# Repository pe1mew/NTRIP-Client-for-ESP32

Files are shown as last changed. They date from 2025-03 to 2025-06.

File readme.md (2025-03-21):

# NTRIP-Client-for-ESP32.

This repository contains the progress in developing a NTRIP client on a ESP32 for the HAN Hydromotive racingteam. 

## License and disclaimer. 

Please note the license at the end of this document. 

# License
This project is free: You can redistribute it and/or modify it under the terms of a Creative Commons Attribution-NonCommercial 4.0 International License (http://creativecommons.org/licenses/by-nc/4.0/) by Remko Welling (https://ese.han.nl/~rwelling) E-mail: remko.welling@han.nl

<br />This work is licensed under a <a rel="license" href="http://creativecommons.org/licenses/by-nc/4.0/">Creative Commons Attribution-NonCommercial 4.0 International License</a>.

# Disclaimer
This project is distributed in the hope that it will be useful, but WITHOUT ANY WARRANTY; without even the implied warranty of MERCHANTABILITY or FITNESS FOR A PARTICULAR PURPOSE.

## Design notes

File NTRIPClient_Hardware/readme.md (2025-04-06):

# Boards

The following boards are under consideration: 

- Wemos S3 - ESP32-S3 https://www.tinytronics.nl/nl/development-boards/microcontroller-boards/met-wi-fi/wemos-s3-esp32-s3
- Waveshare ESP32-S3 Pico Development Board https://www.tinytronics.nl/nl/development-boards/microcontroller-boards/met-wi-fi/waveshare-esp32-s3-pico-development-board

# Architecture

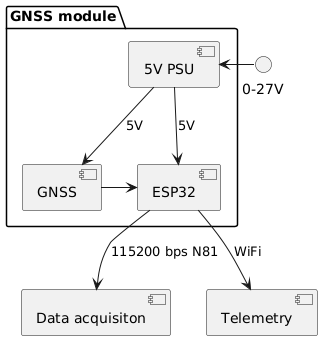
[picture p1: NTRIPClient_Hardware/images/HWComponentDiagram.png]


*figure 1: Component diagram*

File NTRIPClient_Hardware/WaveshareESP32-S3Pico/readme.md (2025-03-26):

# Waveshare ESP32-S3 Pico Development Board

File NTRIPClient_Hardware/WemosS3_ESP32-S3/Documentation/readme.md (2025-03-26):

# Wemos S3 ESP32-S3 documentation 

The following documents have been retrieved from https://www.wemos.cc/en/latest/s3/s3.html at 26-3-2025
 - dim_s3_v1.0.0.pdf
 - esp32-s3-wroom-1_wroom-1u_datasheet_en.pdf
 - s3_v1.0.0_1_16x16.jpg
 - s3_v1.0.0_2_16x16.jpg
 - s3_v1.0.0_4_16x9.jpg
 - sch_s3_v1.0.0.pdf
 
The following documents have been retrieved from https://probots.co.in/esp32-s3-devkitc-1-development-board-wireless-module-wifi-bluetooth.html at 26-3-2025
 - \_ESP32-S3-DevKitC_Dimensions.jpg

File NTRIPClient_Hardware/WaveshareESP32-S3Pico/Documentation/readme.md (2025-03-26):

# Documentation

[Wiki](https://www.waveshare.com/wiki/ESP32-S3-Pico) https://www.waveshare.com/wiki/ESP32-S3-Pico

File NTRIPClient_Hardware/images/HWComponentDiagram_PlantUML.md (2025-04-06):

# PLantUML code for component diagram HWComponentDiagram.png



```
@startuml

package "GNSS module" {
  [5V PSU]
  [GNSS]
  [ESP32]
}

[GNSS] -right-> [ESP32]
[ESP32] --> [Data acquisiton] : 115200 bps N81
[ESP32] --> [Telemetry] : WiFi
[5V PSU] --> [ESP32] : 5V
[5V PSU] --> [GNSS] : 5V

"0-27V" -right-> [5V PSU]

@enduml
```

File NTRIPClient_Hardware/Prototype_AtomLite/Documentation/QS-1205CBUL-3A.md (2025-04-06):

# DC-DC Step Down Module 6-24V 12V 24V to 5V 3A Power Supply Charger QS-1205CBUL-3A



 - Brand: QSKJ
 - Model: [QS-1205CBUL-3A](https://www.qskj.cc/shop/dc-dc-step-down-module-6-24v-12v-24v-to-5v-3a-power-supply-charger-qs-1205cbul-3a-6687)
 
## Images.

 - [QS-1205CBUL-3A_top.jpg](QS-1205CBUL-3A_top.jpg)
 - [QS-1205CBUL-3A_front.jpg](QS-1205CBUL-3A_front.jpg)
 - [QS-1205CBUL-3A_bottom.jpg](QS-1205CBUL-3A_bottom.jpg)

## Features:

 - High quality USB port.
 - Output voltage indicator (RED).
 - The max output current 3A, long time use 2.1A, enough use.
 - New design, 3 solid state ceramic capacitors (MLCC).
 - Synchronous rectification, High efficiency, 6.5V to 5V 0.7A can up to 97.5%, 12V to 5V 1A can up to 94%.
 - Flat copper inductor, improve conversion efficiency
 - With output overvoltage protection. There is 1.5A fuse, output 5V have 300W TVS tube protect your USB device.
 - Using the latest USB identification circuit, perfectly compatible with IPHONE, the most of Android phones, IPAD etc.
 - Input with reverse polarity protection diode, will not damage when input connect incorrect.

## Parameters:

 - Input voltage: DC 6-24V
 - Output voltage: 5.1-5.2V
 - Output current: 3A MAX 
 - Switch frequency:  500KHz
 - Size：26.4(L)*15(W)*7.4(H)  mm
 - Output ripple: 10mV around (12V to 5V3A) 20M bandwidth
 - Output indicator: Output voltage indicator is red
 - Full load temperature: 30 Celsuis
 - Static current: 0.85 mA
 - Load regulation:  ± 1%
 - Voltage Regulation:  ± 0.5%
 - Dynamic response speed:  5% 200uS
 - Connection mode:  Welding
 - Input mode:  Welding
 - Output mode: US
 - Output overvoltage protection: Yes, input 1.5A fuse, output 5V have 300W TVS tube clamp protection.
 - Output short circuit protection: Yes, but please do not short circuit for a long time
 - Input reverse polarity protection: Yes, there is reverse polarity protection diode
 - Module Properties:  non-isolated buck module (BUCK) synchronous rectification
 - Conversion efficiency:  can up to 97.5% (6.5V step down to 5V 0.7A) (after short reverse protection and fuses test value)
 - Ultra-low static current, 0.85 mA only. Do not need to add swith when connected to the car battery, can be connected to car cigarette lighter cable or ACC power supply cable.
 - Operating temperature: Industrial grade (-40 Celsuis to + 85 Celsuis) (the higher the ambient temperature, the lower the output power)

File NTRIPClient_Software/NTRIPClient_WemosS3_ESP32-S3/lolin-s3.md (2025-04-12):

# Key Pin Assignments for LOLIN S3:

UART (Serial Communication):
 - UART0 (Default Serial):
   - TX: GPIO1
   - RX: GPIO3
 - UART1:
   - TX: GPIO19
   - RX: GPIO20
 - UART2:
   - TX: GPIO17
   - RX: GPIO18

I2C (Default):
 - SDA: GPIO8
 - SCL: GPIO9

SPI (Default):
 - SCK:  GPIO36
 - MISO: GPIO37
 - MOSI: GPIO35
 - CS:   GPIO34

WS2812 RGB LED:
 - Data Pin: GPIO38 (Onboard WS2812 RGB LED)

Buttons:
 - BOOT Button: GPIO0 (Can be used as an input)

Analog Pins (ADC):
 - ADC1: GPIO1, GPIO2, GPIO3, GPIO4, GPIO5, GPIO6, GPIO7
 - ADC2: GPIO10, GPIO11, GPIO12, GPIO13, GPIO14, GPIO15

PWM (LED Control):
 - Any GPIO pin can be used for PWM output.

Power Pins:
 - 5V: 5V pin
 - 3.3V: 3.3V pin
 - GND: Ground pins

Other Pins:
 - GPIO38: Onboard WS2812 RGB LED
 - GPIO39: Input-only pin (can be used for buttons or sensors)

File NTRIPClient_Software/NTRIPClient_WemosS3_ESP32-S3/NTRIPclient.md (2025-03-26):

# NTRIP Client Operation Manual

## Introduction
The NTRIP (Networked Transport of RTCM via Internet Protocol) client is designed to receive RTCM correction data from an NTRIP caster, provide it to GNSS receivers for improved positioning accuracy, and send position information of the GNSS receiver to a MQTT broker. 

## Requirements
- A device running the NTRIP client firmware (e.g., ATOM Lite).
- Access to an NTRIP caster with valid credentials (host, port, username, password, and mountpoint).
- Access to an MQTT broker with valid credentials (host, port, username, password, and topic).
- A stable internet connection (Wi-Fi or other supported methods).
- A GNSS receiver capable of processing RTCM correction data.

## Setup Instructions

### 1. Configure Wi-Fi
1. When the NTRIP client boots up, it tries to connect to a previously saved WiFi network.
2. If no known network is found, it creates a WiFi Access Point (AP) with:
   - **SSID**: "NTRIPClient_Config"
   - **Password**: none
3. Connect your phone or computer to this network.
4. Open a browser and go to 192.168.4.1.
5. Select your WiFi network, enter the password, and save the settings.

When the NTRIP client is connected to a WiFi network:
1. the config menu can be invoked by pressing the button on the NTRIP client for more than 3 seconds. 
2. Connect your computer to the same network as the NTRIP client. 
3. Open a browser and go to the IP-address of the NTRIP client. 
4. Select a WiFi network, enter the password, and save the settings.

### 2. Configure NTRIP Caster Details
1. Provide the following details for the NTRIP caster:
   - **Host**: The hostname or IP address of the NTRIP Caster (e.g., `caster.example.com`)
   - **Port**: The port number for the NTRIP caster (e.g., `2101`)
   - **Mountpoint**: Name of the moint point where the RTCM data will be retrieved (e.g., `RTCM3`)
   - **Username and password**: Credentials for authenticating with the NTRIP Caster (if required)
2. Save the configuration.

### 3. Start the NTRIP Client
1. Initiate the connection to the NTRIP caster.
2. Verify that the device successfully connects and starts receiving RTCM data.

### 4. Connect to GNSS Receiver
1. Ensure the GNSS receiver is properly connected to the device (e.g., via UART or other supported interfaces).
2. Verify that the GNSS receiver is receiving RTCM correction data.

### 5. Configure MQTT Client
1. Access the device's configuration interface.
2. Provide the following MQTT broker details:
   - **Broker Address**: The hostname or IP address of the MQTT broker (e.g., `mqtt.example.com`).
   - **Port**: The port number for the MQTT broker (e.g., `1883`).
   - **Username and Password**: Credentials for authenticating with the MQTT broker (if required).
   - **Topic**: The MQTT topic where the device will publish data (e.g., `ntrip/status`).
3. Save the configuration.

### Purpose of MQTT Client
The MQTT client allows the NTRIP client to publish status updates and diagnostic information to an MQTT broker. This enables remote monitoring and integration with IoT platforms or dashboards.

### JSON Structure of Published Data
The NTRIP client publishes data in JSON format to the configured MQTT topic. Below is the structure of the JSON payload:

```json
{
  "timestamp": "2023-01-01T12:00:00Z", // ISO 8601 timestamp of the message
  "status": "connected",              // Current connection status (e.g., "connected", "disconnected")
  "ntrip": {
    "host": "caster.example.com",     // NTRIP caster hostname
    "port": 2101,                     // NTRIP caster port
    "mountpoint": "RTCM3"             // NTRIP mountpoint in use
  },
  "gnss": {
    "rtcm_received": true,            // Whether RTCM data is being received
    "last_rtcm_time": "2023-01-01T11:59:50Z" // Timestamp of the last RTCM message received
  }
}
```

### Example Use Case
- Use the MQTT data to monitor the connection status of the NTRIP client.
- Integrate the JSON payload into a dashboard to visualize real-time data.
- Trigger alerts if the client disconnects or stops receiving RTCM data.

## Troubleshooting
- **No Internet Connection**: Check Wi-Fi credentials and signal strength.
- **Failed to Connect to NTRIP Caster**: Verify the host, port, and credentials.
- **No RTCM Data on GNSS Receiver**: Check the connection between the device and the GNSS receiver.

## Additional Notes
- Ensure the device's firmware is up-to-date for optimal performance.
- Contact your NTRIP caster provider for assistance with credentials or mountpoint details.

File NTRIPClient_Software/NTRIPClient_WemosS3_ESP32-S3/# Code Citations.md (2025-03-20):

# Code Citations

## License: LGPL_3_0
https://github.com/GLAY-AK2/NTRIP-client-for-Arduino/tree/875298f5fa1c4ec84929b0c54364f77d5df7e081/src/NTRIPClient.cpp

```
0\r\n"
        "User-Agent: NTRIPClient for Arduino v1.0\r\n"
    );
    unsigned long timeout = millis();
    while (available() == 0) {
        if (millis() - timeout > 5000) {
            Serial.
```

## License: unknown
https://github.com/heyno/arduino/tree/143c22816d5a8fa4521b3c6ef67941aee86f4876/libraries/NTRIP-client-for-Arduino-master/src/NTRIPClient.cpp

```
Arduino v1.0\r\n"
    );
    unsigned long timeout = millis();
    while (available() == 0) {
        if (millis() - timeout > 5000) {
            Serial.println("Client Timeout !");
            stop();
```

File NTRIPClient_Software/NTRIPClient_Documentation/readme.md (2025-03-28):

# Software manual NTRIP Client

The NTRIP client is developed for the [Hydromotive project](https://www.hydromotive.nl/) to enable cm precison location and timing. 

The **NTRIP client** (Networked Transport of RTCM via Internet Protocol) is used to receive real-time correction data for a **GNSS (Global Navigation Satellite System)** receiving. By connecting to an **NTRIP caster** (a server that distributes correction data from an NTRIP base station or network) the NTRIP data is received and forwarded to the connected GNSS receiver.

The position and timing information from the GNSS receiver is published using the **MQTT (Message Queuing Telemetry Transport)** protocol on a **MQTT broker** for post processing purposes and live monitoring. 

### **How this NTRIP client Works:**
1. The **GNSS receiver** connects to an **NTRIP client**.
2. The **NTRIP client** sends a request to an **NTRIP caster** over the internet.
3. The **NTRIP caster** provides **RTCM correction data** from a nearby base station or network.
4. The **GNSS receiver** uses this data to correct its position in real time.
5. The **MQTT client** connects to an **MQTT broker** (server).
6. The **MQTT client** **subscribes** to a topic (e.g., "ntripclient").
7. The **MQTT client** publishes position and timing data to the topic
8. The broker **forwards** messages to all subscribed clients that use the data.
9. The **MQTT client** publishes time data to the data ackuisition unit of the Hydromotive vehicle. 

# NTRIP Client operation.
After powering the NTRIP Client, WiFi connection is initiated. At a successfull WiFi connection, the NTRIP caster is connected and the mountpoint table is requested. When the mointpoint table is received, the mointpoint is connected and RTCM data that is received will be forwarded to the GNSS receiver. When a valid set of NMEA sentences is received from the GNSS receiver, a aggregate of time, postion and accuracy data is send to the MQTT broker. 

### WiFi Connection failure
When the **Wifi connection fails at startup**, a WiFi accesspoint and the configuration portal is activated. The configuration panel can be accesses after connecting to the Accesspoint and ip-address 192.168.4.1.

When the **WiFi connection fails during operation**, reconnects are attempted. After a period of time, a WiFi accesspoint and the configuration portal is activated for configuration. 

### Connection failure with NTRIP caster 
When the **Connection fails with the NTRIP caster**, a restart of the NTRIP Client is executed to attempt to recover the connection.

### Connection failure with MQTT broker
When the **Connection fails with the MQTT broker**, an attempt is made to reconnect. Because NTRIP correction data for the GNSS receiver has priority over MQTT, the ocnnection NTRIP is retained and the NTRIP Client will not restart. 

### NTRIP Client Configuration
> The NTRIP Client can be configured from Platform.io by writing the config file `config.json` in de `data` directory to SPIFFS. Instructions can be found in `data_template/readme.md`.

The NTRIP Client can be configured using WiFi manager: 
 - During normal operation, WiFi manager can be activated by **pressing the config-button longer than 3 seconds**. 
 - When WiFi the connection fails, an Accesspoint is activated where the WiFi manager can be accessed. 

# WiFi manager

WiFi Manager manages al configureable items of the NTRIP Client in a browser. The WiFi manager is invoked after a connect failure of the WiFi at boot, or after pressing the **Configuration button** for a period longer than 3 seconds. 

In the following paragraphs the menus of WiFi manager are discussed.

## Main menu

Main memu is the start screen when entering WiFi manager.

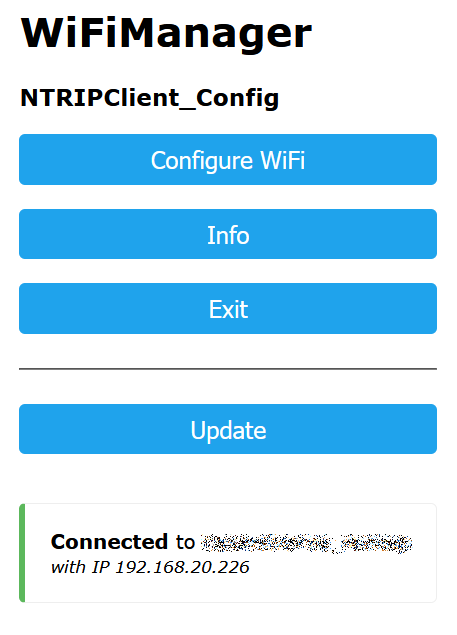
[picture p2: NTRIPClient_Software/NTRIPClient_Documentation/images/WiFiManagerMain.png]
WiFiManager


*Figure 1: Main menu of WiFimanager for NTRIP Client.*

The main menu allows access to the following screens: 
 1. **Configure WiFi**: Configure NTRIP Client settings. 
 2. **Info**: System information. 
 3. **Exit**: Store settings and reboot NTRIP client. 
 4. **Update**: Update software image.
 
## Configure NTRIP Client settings

WiFi manager allows for full configuration of the NTRIP Client. The following parameters can be configured using Wifi manager: 

 - WiFi:
   - **ssid**: SSID of the WiFi Accesspoint
   - **password**: Password for the WiFi Accesspoint
 - NTRIP Client:
   - **host**: hostname of the NTRIP Caster
   - **tcp-port**: tcp-port for the broker *(Default: 2101)*
   - **mntpnt**: mountpoint
   - **username**: username for the NTRIP caster
   - **password**: password for the user
 - MQTT Client:
   - **broker**: *IP-address* of the MQTT broker **(No URL!)**
   - **port**: tcp-port for the broker *(Default: 1883)*
   - **topic**: Topic where the data will be published *(e.g. ntripclient)*
   - **username**: username for the MQTT broker
   - **password**: password for the user

The configuration items are permanently stored on the NTRIP Client. 

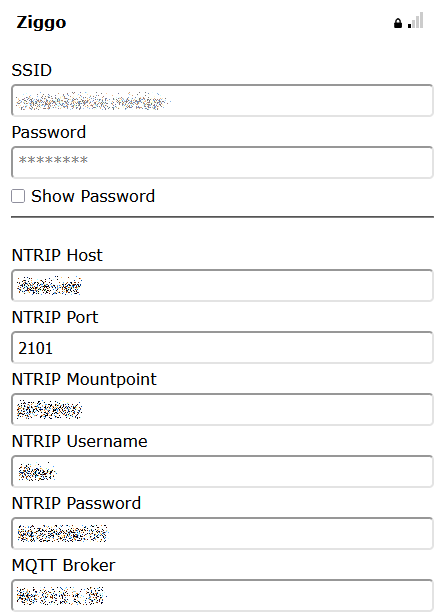
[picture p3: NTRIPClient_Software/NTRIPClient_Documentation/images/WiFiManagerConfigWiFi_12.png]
WiFiManagerConfigWiFi_12

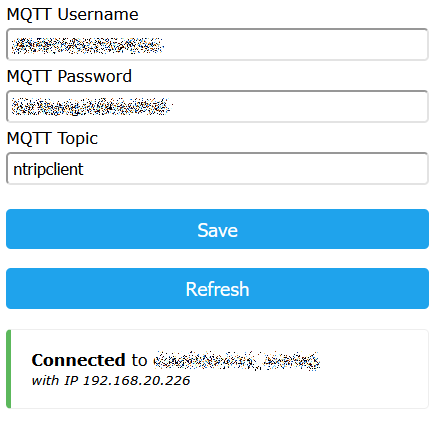
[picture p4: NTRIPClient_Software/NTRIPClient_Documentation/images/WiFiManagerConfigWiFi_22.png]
WiFiManagerConfigWiFi_12


*Figure 2: Settings menu of WiFi manager for NTRIP Client.*

## Info

WiFi manager shows system information of the NTRIP Client: 

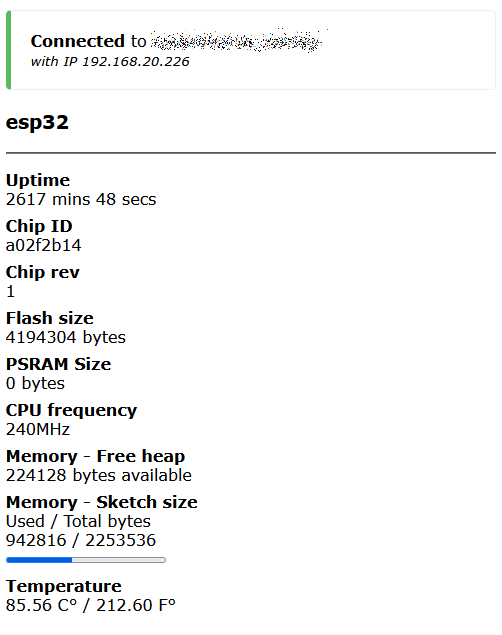
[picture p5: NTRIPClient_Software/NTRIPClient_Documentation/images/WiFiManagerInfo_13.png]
WiFiManagerInfo_13

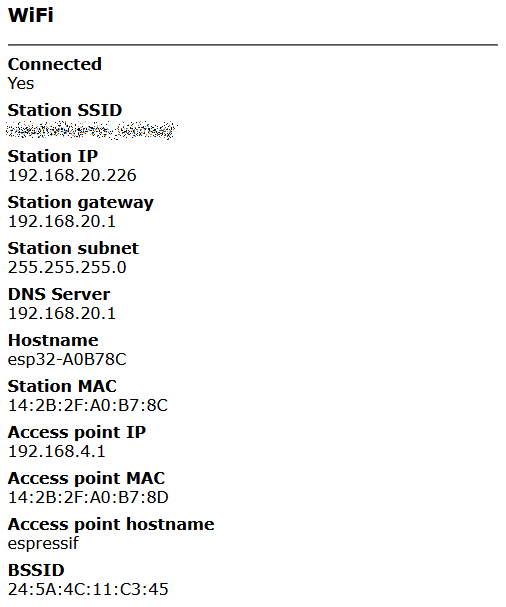
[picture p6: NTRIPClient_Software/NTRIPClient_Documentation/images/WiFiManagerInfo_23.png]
WiFiManagerInfo_23

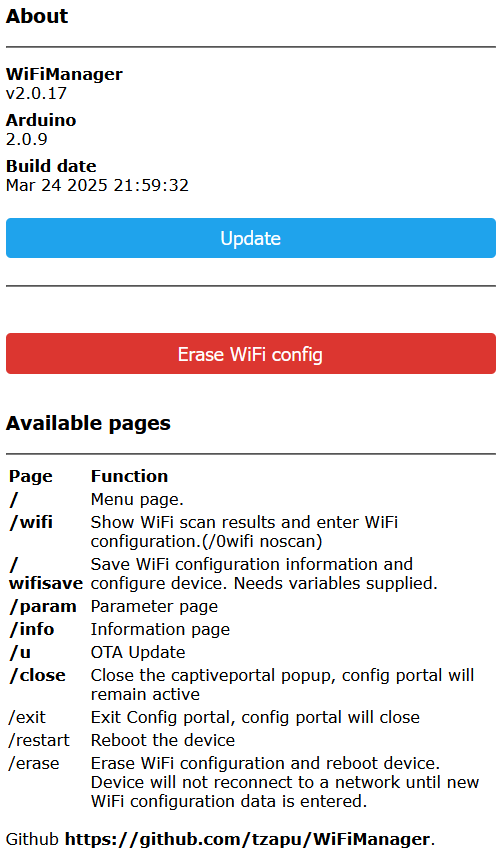
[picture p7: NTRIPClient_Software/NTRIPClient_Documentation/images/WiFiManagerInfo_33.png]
WiFiManagerInfo_33


*Figure 3: Information menu of WiFi manager for NTRIP Client.*

## Exit

To close WiFo manager, click **Exit** to save teh settings and restart NTRIP Client. 

## Update

In the Update menu the firmware of the NTRIP Client can be updated. 
> **This feature is not tested. Use with care!**

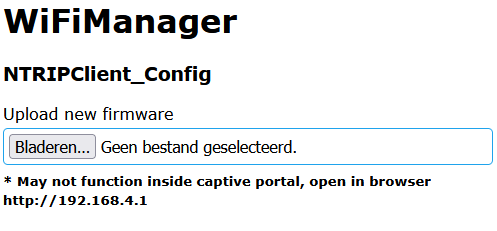
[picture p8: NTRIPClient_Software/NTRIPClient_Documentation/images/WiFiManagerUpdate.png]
WiFiManagerUpdate


*Figure 4: Update menu of WiFi manager for NTRIP Client.*

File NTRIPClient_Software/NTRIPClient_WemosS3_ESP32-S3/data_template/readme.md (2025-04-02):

# Configuration file config.json

The `config.json` file is used to store the settings required for the Ntrip client to function properly. It contains three main sections: `wifi`, `ntrip`, and `mqtt`. 

```json
{
    "wifi": {
        "ssid": "ssid",
        "password": "wifi_password"
    },
    "ntrip": {
        "host": "host",
        "port": 2101,
        "mntpnt": "mountpoint",
        "user": "ntrip_user",
        "passwd": "ntrip_user_password"
    },
    "mqtt": {
        "broker": "broker",
        "port": 1883,
        "topic": "ntripclient",
        "user": "mqtt_user",
        "passwd": "mqtt_user_password"
    }
}
```

## Configuration Details

Below is a detailed explanation of each section and its name-value pairs:

### WiFi Configuration (`wifi`)
- **ssid**: The SSID (name) of the WiFi network to connect to.
- **password**: The password for the WiFi network.

### NTRIP Configuration (`ntrip`)
- **host**: The hostname or IP address of the NTRIP caster.
- **port**: The port number of the NTRIP caster (default is usually 2101).
- **mntpnt**: The mountpoint to connect to on the NTRIP caster.
- **user**: The username for NTRIP authentication.
- **passwd**: The password for NTRIP authentication.

### MQTT Configuration (`mqtt`)
- **broker**: The *IP address* of the MQTT broker. *The hostname of the broker cannot be used here!*
- **port**: The port number of the MQTT broker (default is 1883).
- **topic**: The MQTT topic to publish or subscribe to.
- **user**: The username for MQTT authentication.
- **passwd**: The password for MQTT authentication.

## Instructions

### Step 1: Prepare the Configuration File
1. Copy the directory `data_template` and its contents to a new directory named `data`.
2. Open `data/config.json` and update the values for `wifi`, `ntrip`, and `mqtt` with the required credentials and settings for your environment.

### Step 2: Remove Unnecessary Files
- Delete the file `data/readme.md` to ensure it is not uploaded to the SPIFFS filesystem.

### Step 3: Upload the Configuration to the ESP32
1. Open a terminal in PlatformIO.
2. Run the following command to compile and upload the SPIFFS filesystem to your ESP32:
   ```bash
   pio run --target uploadfs
   ```
3. Once the upload is complete, the ESP32 will use the settings from `config.json` to connect to the WiFi network, NTRIP caster, and MQTT broker.

### Notes
- Ensure that the ESP32 has sufficient permissions and connectivity to access the specified WiFi network, NTRIP caster, and MQTT broker.
- Double-check the JSON syntax in `config.json` to avoid errors during runtime.

This configuration file allows the Ntrip client to operate seamlessly by providing all necessary credentials and connection details in one place.

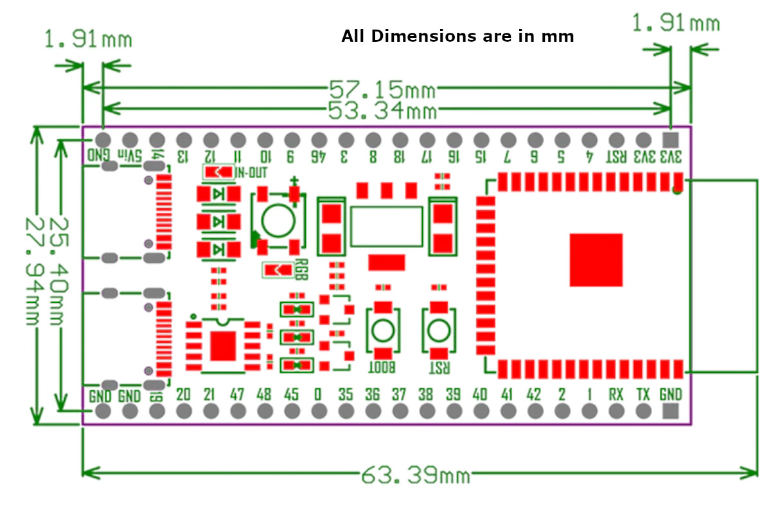
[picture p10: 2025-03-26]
NTRIPClient_Hardware/WemosS3_ESP32-S3/Documentation/_ESP32-S3-DevKitC_Dimensions.jpg

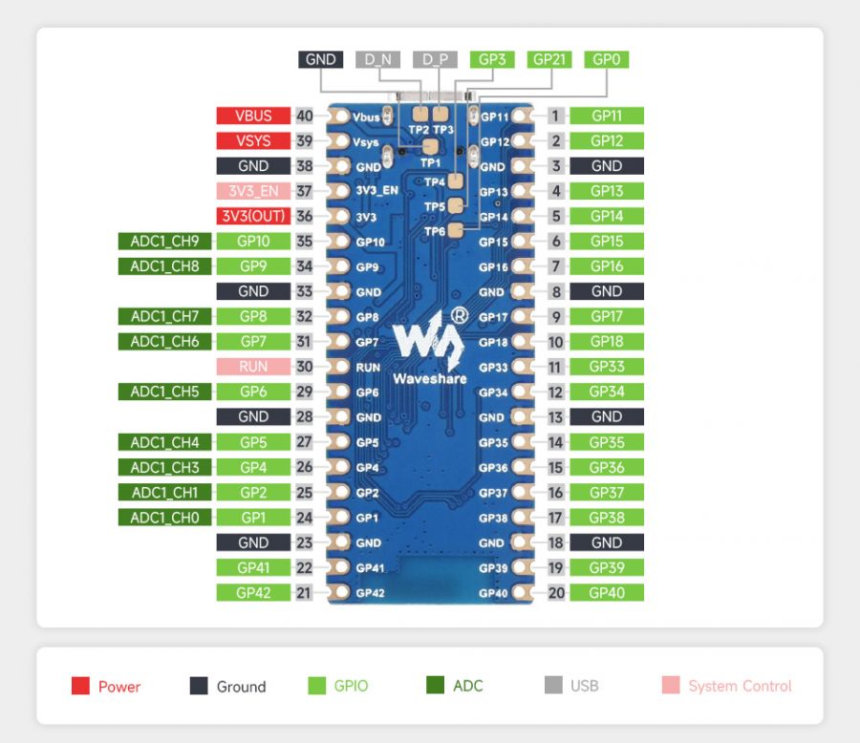
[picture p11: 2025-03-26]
NTRIPClient_Hardware/WaveshareESP32-S3Pico/Documentation/900px-ESP32-S3-Pico-details-inter-1.jpg

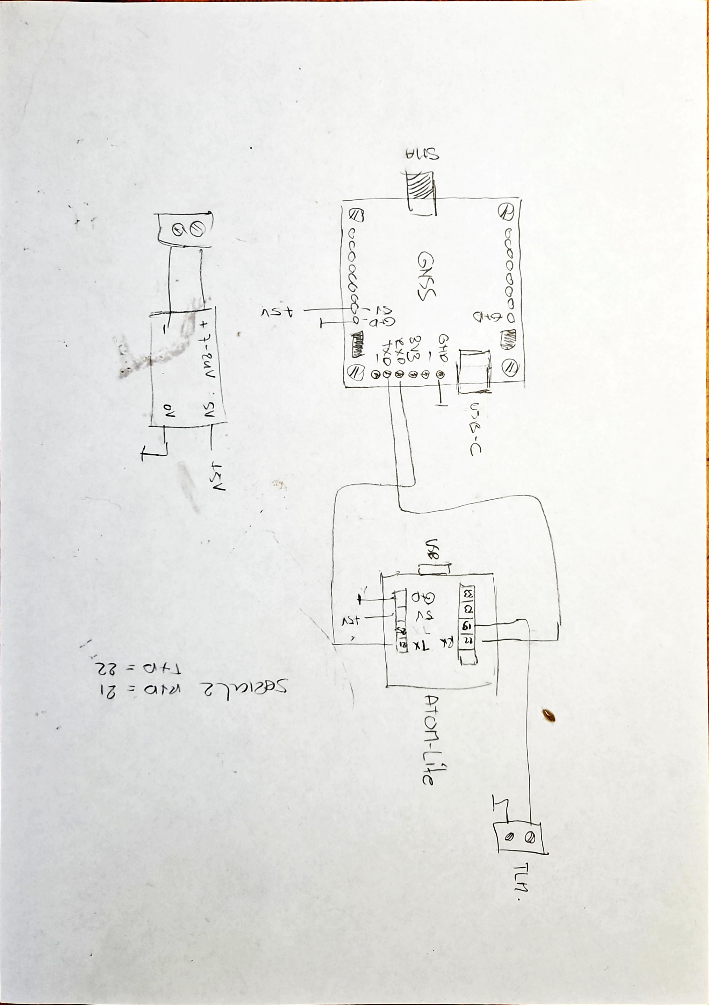
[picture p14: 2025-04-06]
NTRIPClient_Hardware/Prototype_AtomLite/Documentation/PrototypeSchema.jpg

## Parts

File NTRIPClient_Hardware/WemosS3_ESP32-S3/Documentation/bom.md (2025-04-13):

RS PRO, 5.08mm Pitch, 4 Way, Right Angle, Pluggable Terminal Block, Plug, Through Hole, Screw Termination
RS-stocknr.: 897-1216
Fabrikant: RS PRO
https://nl.rs-online.com/web/p/pluggable-terminal-blocks/8971216
1,33 \* 5

RS PRO, 5mm Pitch, 4 Way, , Pluggable Terminal Block, Header, Through Hole, Screw Termination
RS-stocknr.: 144-4283
Fabrikant: RS PRO
https://nl.rs-online.com/web/p/pluggable-terminal-blocks/1444283
0,434 \* 10

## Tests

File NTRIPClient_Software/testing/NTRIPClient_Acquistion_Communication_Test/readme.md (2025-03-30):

# NTRIPClient --> Acquistion unit, Communication Test

This unit test, tests the CRC-16 calculation for the day-time-stamp that is sent to the Acquistion unit by the NTRIP client.

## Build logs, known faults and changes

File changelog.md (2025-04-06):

# Changelog

All notable changes to this project are documented in this file.

The format is based on [Keep a Changelog](https://keepachangelog.com/), and this project adheres to [Semantic Versioning](https://semver.org/).

## [Unreleased]

### Added
- *Nothing.*

### Changed
- *Nothing.*

### Fixed
- *Nothing.*

### Removed

## [Version 0.0.1] - 2025-04-06

### Added
- Connects over WiFi to the internet. 
- Receives NTRIP data from caster and forwards to GNSS module.
- Forwards postion data and metadata over MQTT to a broker.
- Sends siral timestamp with CRC-16 over serial port.
- WiFi, NTrip-client, and MQTT-client ar configureable over WiFi Manager.

### Changed
- *Nothing.*

### Fixed
- *Nothing.*

### Removed
- *Nothing.*

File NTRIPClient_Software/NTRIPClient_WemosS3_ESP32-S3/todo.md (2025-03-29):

# Todolist for software

29-3-2025

|#|**Done**  |**Description** |
|-|---|---|
|1|23-3-3035 |Convert lat in MQTT message to DD.DDDDDDDDDD|
|2|29-3-2025-|Convert lon in MQTT message to DD.DDDDDDDDDD|

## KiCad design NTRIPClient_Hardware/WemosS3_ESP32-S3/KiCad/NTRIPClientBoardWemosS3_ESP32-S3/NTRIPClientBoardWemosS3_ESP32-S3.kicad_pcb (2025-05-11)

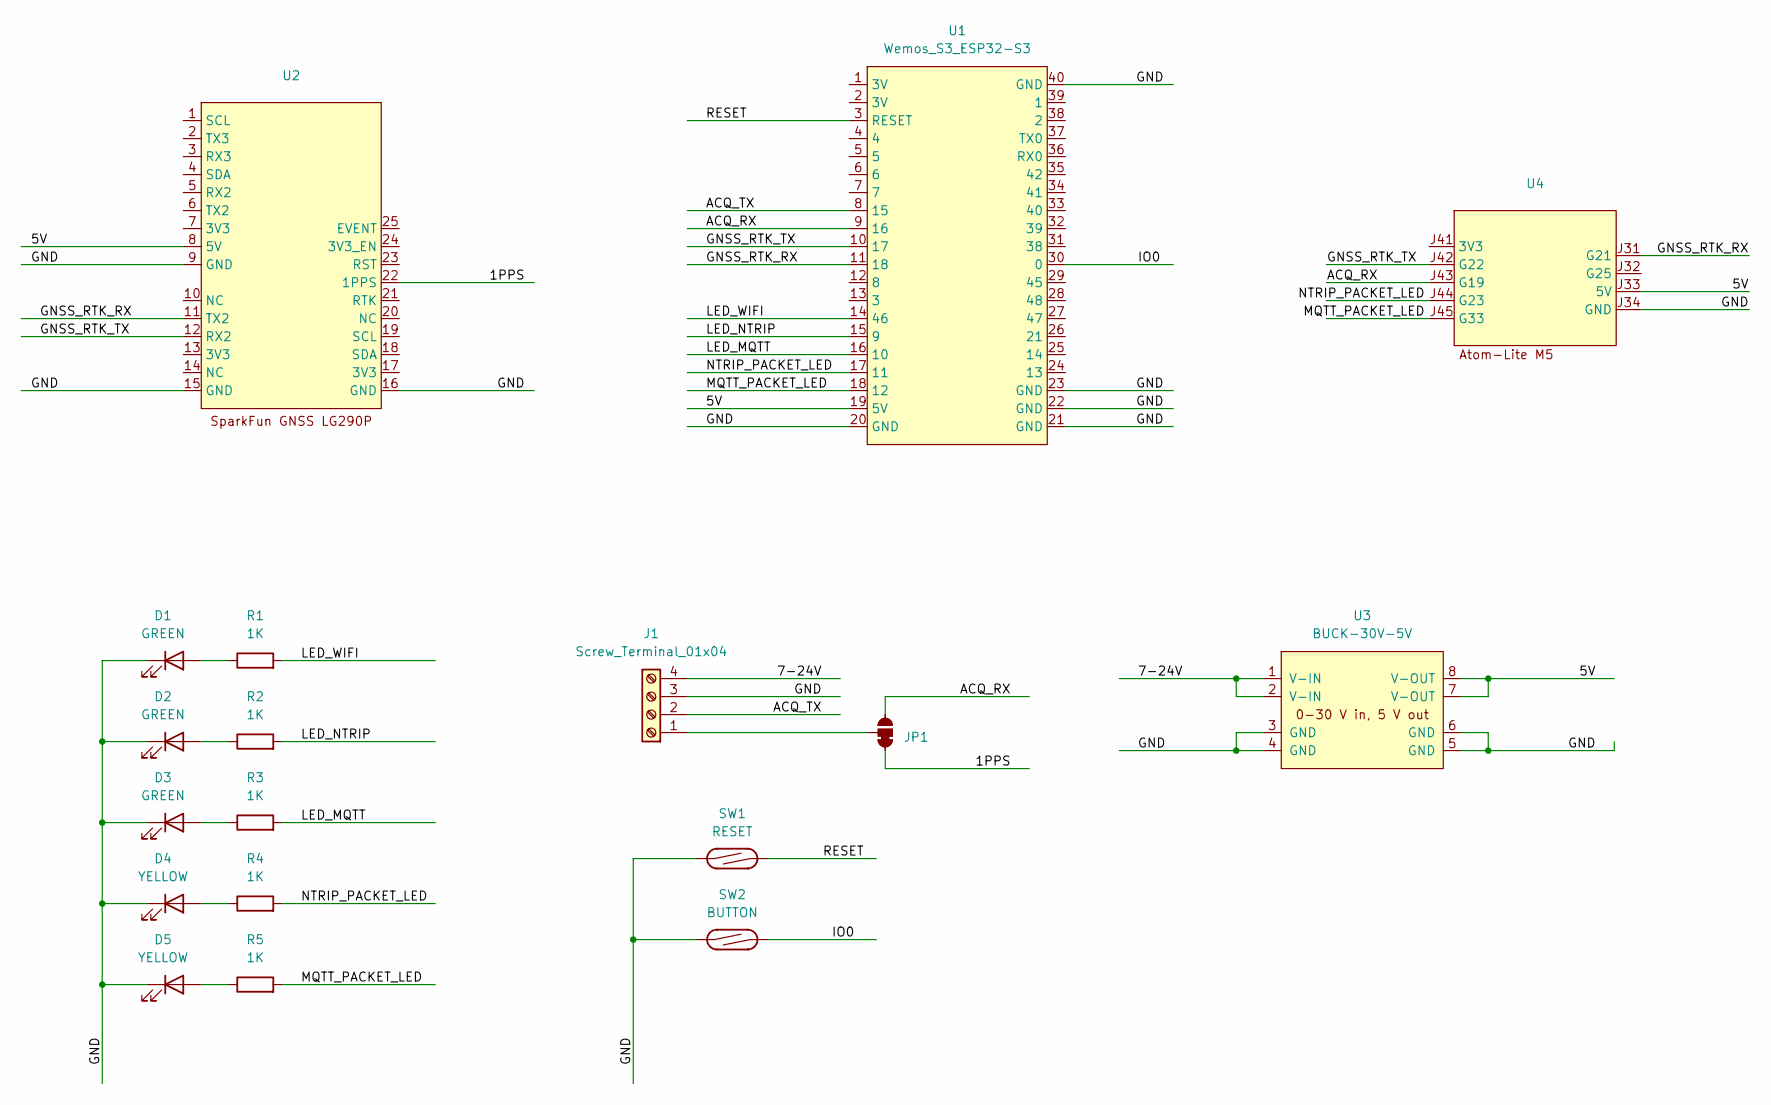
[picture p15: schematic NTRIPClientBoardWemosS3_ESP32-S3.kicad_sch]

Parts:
D1, D2, D3: GREEN; LED_1206_3216Metric
D4, D5: YELLOW; LED_1206_3216Metric
J1: Screw_Terminal_01x04; PhoenixContact_MSTBVA_2,5_4-G_1x04_P5.00mm_Vertical
JP1: Jumper_3_NC-1_Trace
R1, R2, R3, R4, R5: 1K; R_1206_3216Metric
SW1: RESET; SW_SPST_REED_20mm
SW2: BUTTON; SW_SPST_REED_20mm
U1: Wemos_S3_ESP32-S3
U2: SparkFun_GNSS_LG290P
U3: BUCK-30V-5V
U4: Atom-Lite_M5

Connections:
/1PPS: JP1.1 (A), U2.22 (1PPS)
/5V: U1.19 (5V), U2.8 (5V), U3.7 (V-OUT), U3.8 (V-OUT), U4.J33 (5V)
/7-24V: J1.4, U3.1 (V-IN), U3.2 (V-IN)
/ACQ_RX: JP1.3 (C), U1.9 (16), U4.J43 (G19)
/ACQ_TX: J1.2, U1.8 (15)
/GND: D1.1 (K), D2.1 (K), D3.1 (K), D4.1 (K), D5.1 (K), J1.3, SW1.1, SW2.1, U1.20 (GND), U1.21 (GND), U1.22 (GND), U1.23 (GND), U1.40 (GND), U2.9 (GND), U2.15 (GND), U2.16 (GND), U3.3 (GND), U3.4 (GND), U3.5 (GND), U3.6 (GND), U4.J34 (GND)
/GNSS_RTK_RX: U1.11 (18), U2.11 (TX2), U4.J31 (G21)
/GNSS_RTK_TX: U1.10 (17), U2.12 (RX2), U4.J42 (G22)
/IO0: SW2.2, U1.30 (0)
/LED_MQTT: R3.2, U1.16 (10)
/LED_NTRIP: R2.2, U1.15 (9)
/LED_WIFI: R1.2, U1.14 (46)
/MQTT_PACKET_LED: R5.2, U1.18 (12), U4.J45 (G33)
/NTRIP_PACKET_LED: R4.2, U1.17 (11), U4.J44 (G23)
/RESET: SW1.2, U1.3 (RESET)
unnamed: D1.2 (A), R1.1
unnamed: D2.2 (A), R2.1
unnamed: D3.2 (A), R3.1
unnamed: D4.2 (A), R4.1
unnamed: D5.2 (A), R5.1
unnamed: J1.1, JP1.2 (B)

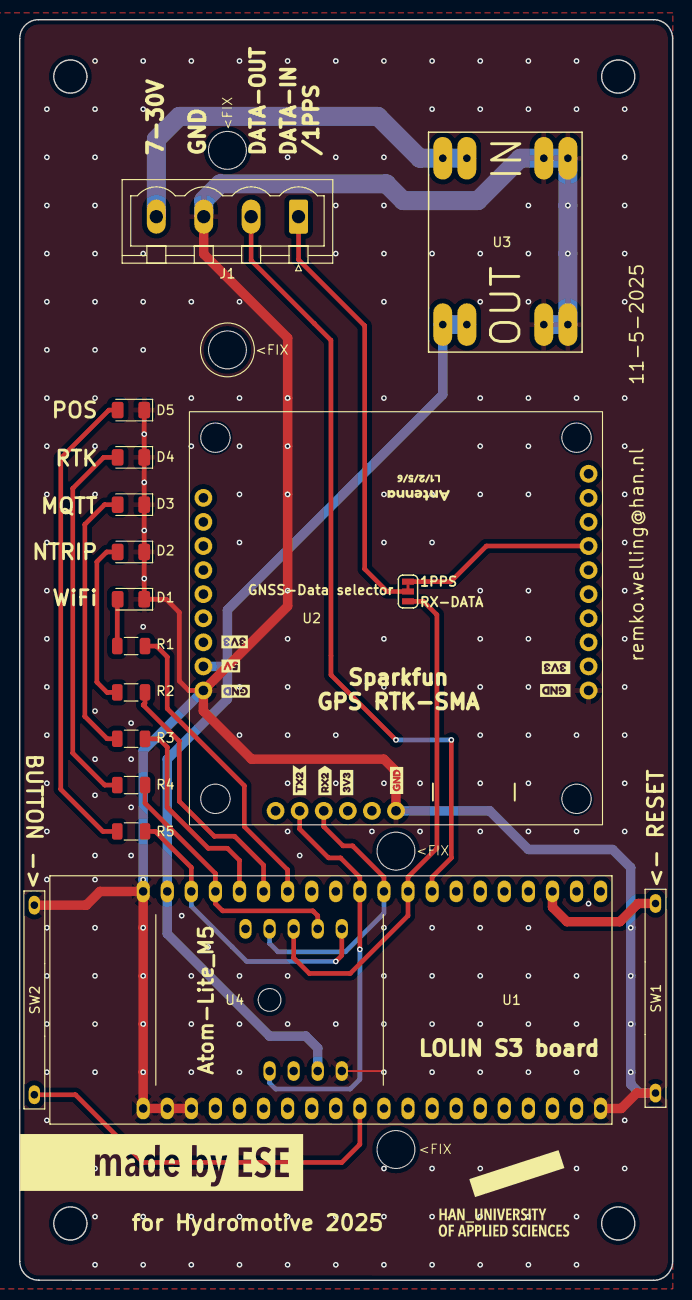
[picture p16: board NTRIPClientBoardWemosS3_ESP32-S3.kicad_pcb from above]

Board: 2 copper layers, 68.9 x 133.0 mm, 18 parts (0 on the bottom side), 21 nets.

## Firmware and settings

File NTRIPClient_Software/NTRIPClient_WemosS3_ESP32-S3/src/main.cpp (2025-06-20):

#define Debug  // Add this line to enable debug information

// --------------------------------------------------------------------
//   This file is part of the PE1MEW NTRIP Client.
//
//   The NTRIP Client is distributed in the hope that 
//   it will be useful, but WITHOUT ANY WARRANTY; without even the 
//   implied warranty of MERCHANTABILITY or FITNESS FOR A PARTICULAR 
//   PURPOSE.
// --------------------------------------------------------------------*/

/*!
   
 \file main.cpp
 \brief Main file for the NTRIPClient project
 \author Remko Welling (PE1MEW) 

 This file was based upon the following work:
  - [NTRIP-client-for-Arduino](https://github.com/GLAY-AK2/NTRIP-client-for-Arduino)
  - [ESPNTRIPClient](https://github.com/klstronics/ESPNTRIPClient)

 The original work is adapted for ATOM Lite ESP32 board and the following changes were made:
  - Added WiFiManager for easy configuration
  - Added SPIFFS for storing configuration
  - Added NeoPixel LED for status indication
  - Added button for configuration mode
  - Added GGA sentence parsing and sending
  - Added SourceTable request
  - Added debug information

  The NTRIPClient is a simple NTRIP client for the ESP32 platform. It is designed to connect to an NTRIP server and receive RTCM data. 
  The client can be configured using a button to enter configuration mode and set the WiFi and NTRIP server settings. 
  The client will connect to the NTRIP server and request the SourceTable to get the available mountpoints. 
  The client will then request the raw data from the specified mountpoint using the provided credentials. 
  The client will also read GGA sentences from the serial interface and send them to the NTRIP server. 
  The client will indicate the status using a NeoPixel LED. 

  The client will automatically reconnect to the NTRIP server if the connection is lost. 

  The client will store the configuration in SPIFFS and load it on startup. 

  The client will enter configuration mode if the button is pressed for 3 seconds. 

  The client will turn off the LED after 500ms if no data is received. 

  The client will print debug information if the Debug flag is set. 

  The client will restart if the NTRIP server is not reachable. 

  The client will restart if the mountpoint request fails. 

  The client will restart if the mountpoint request is successful but no data is received. 

  The client will restart if the mountpoint request is successful but the connection is lost. 

   
*/

#include <WiFi.h>
#include <WiFiManager.h>
#include "NTRIPClient.h"
#include <PubSubClient.h>
#include <Adafruit_NeoPixel.h>
#include <ArduinoJson.h>
#include <FS.h>
#include <SPIFFS.h>

#include <stdint.h>
#include <string.h>
#include <Arduino.h>

#include "hardwareConfig.h" // Include hardware configuration file
#include "NTRIPClientCRC16.h" // Include the CRC-16 calculation header file

Adafruit_NeoPixel pixels(NUMPIXELS, LED_PIN, NEO_GRB + NEO_KHZ800); ///< NeoPixel LED object
NTRIPClient ntrip_c;        ///< NTRIPClient object
WiFiClient espClient;       ///< WiFi client object
PubSubClient mqttClient(espClient); ///< MQTT client object

// Configuration variables
char _wifiSsid[32] = {'\0'};        ///< WiFi SSID
char _wifiPassword[32] = {'\0'};    ///< WiFi password
char _ntripHost[32] = {'\0'};       ///< NTRIP server host
int  _ntripHttpPort = {0};          ///< NTRIP server port
char _ntripMountPoint[32] = {'\0'}; ///< NTRIP mountpoint
char _ntripUser[32] = {'\0'};       ///< NTRIP username
char _ntripPassword[32] = {'\0'};   ///< NTRIP password
char _mqttBroker[32] = {'\0'};      ///< MQTT broker
char _mqttUser[32] = {'\0'};        ///< MQTT username
char _mqttPassword[32] = {'\0'};    ///< MQTT password
char _mqttTopic[64] = {'\0'};       ///< MQTT topic

// For reading and sending GGA sentences
static char nmeaBuffer[256] = {'\0'};   ///< Buffer to store NMEA sentences
static char ggaBuffer[256] = {'\0'};    ///< Buffer to store GGA sentences
static char rmcBuffer[256] = {'\0'};    ///< Buffer to store RMC sentences
static char vtgBuffer[256] = {'\0'};    ///< Buffer to store VTG sentences
static int nmeaBufferIndex = {0};
bool ggaReceived = false;
bool rmcReceived = false;
bool vtgReceived = false;


// Flag to track receiving state
bool isReceiving = false;          ///< Flag to track if data is being received
unsigned long lastReceiveTime = {0}; ///< Time of last data received in ms

// Button press handling
bool buttonPressed = false;
unsigned long buttonPressTime = {0};
bool configMode = false;

unsigned long lastGGASendTime = 0; ///< Variable to store the last GGA send time
unsigned long sequenceNumber = 0;   ///< Variable to store the sequence number for the JSON data

static bool ntripConnected = false;
static unsigned long ntripConnectAttemptTime = 0;
static const unsigned long ntripConnectRetryInterval = 100; // 100 ms 
static unsigned long ntripLedOffTime = 0;
static bool ntripLedBlinking = false;

static unsigned long mqttLedOffTime = 0;
static bool mqttLedBlinking = false;

IPAddress mqttBrokerIP; // Variable to store the MQTT broker IP address

/**
 * @brief Print the current configuration to the serial output.
 */
void printConfig() {
    Serial.println("Current Configuration:");
    Serial.print("WiFi SSID: ");
    Serial.println(_wifiSsid);
    Serial.print("WiFi Password: ");
    Serial.println(_wifiPassword);
    Serial.print("NTRIP Host: ");
    Serial.println(_ntripHost);
    Serial.print("NTRIP Port: ");
    Serial.println(_ntripHttpPort);
    Serial.print("NTRIP Mountpoint: ");
    Serial.println(_ntripMountPoint);
    Serial.print("NTRIP Username: ");
    Serial.println(_ntripUser);
    Serial.print("NTRIP Password: ");
    Serial.println(_ntripPassword);
    Serial.print("MQTT Broker: ");
    Serial.println(_mqttBroker);
    Serial.print("MQTT Username: ");
    Serial.println(_mqttUser);
    Serial.print("MQTT Password: ");
    Serial.println(_mqttPassword);
    Serial.print("MQTT Topic: ");
    Serial.println(_mqttTopic);
}

/**
 * @brief Load configuration from SPIFFS.
 */
void loadConfig() {
    if (!SPIFFS.begin(true)) {
        Serial.println("[ERROR] Failed to mount file system");
        return;
    }

    File configFile = SPIFFS.open("/config.json", "r");
    if (!configFile) {
        Serial.println("[ERROR] Failed to open config file");
        return;
    }

    size_t size = configFile.size();
    std::unique_ptr<char[]> buf(new char[size]);
    configFile.readBytes(buf.get(), size);

    DynamicJsonDocument doc(1024);
    DeserializationError error = deserializeJson(doc, buf.get());
    if (error) {
        Serial.println("[ERROR] Failed to parse config file");
        return;
    }

    strlcpy(_wifiSsid, doc["wifi"]["ssid"], sizeof(_wifiSsid));
    strlcpy(_wifiPassword, doc["wifi"]["password"], sizeof(_wifiPassword));
    strlcpy(_ntripHost, doc["ntrip"]["host"], sizeof(_ntripHost));
    _ntripHttpPort = doc["ntrip"]["port"];
    strlcpy(_ntripMountPoint, doc["ntrip"]["mntpnt"], sizeof(_ntripMountPoint));
    strlcpy(_ntripUser, doc["ntrip"]["user"], sizeof(_ntripUser));
    strlcpy(_ntripPassword, doc["ntrip"]["passwd"], sizeof(_ntripPassword));
    strlcpy(_mqttBroker, doc["mqtt"]["broker"], sizeof(_mqttBroker));
    mqttBrokerIP.fromString(_mqttBroker); // Convert string to IP address
    strlcpy(_mqttUser, doc["mqtt"]["user"], sizeof(_mqttUser));
    strlcpy(_mqttPassword, doc["mqtt"]["passwd"], sizeof(_mqttPassword));
    strlcpy(_mqttTopic, doc["mqtt"]["topic"], sizeof(_mqttTopic));

    #ifdef Debug
    printConfig();
    #endif
}

/**
 * @brief Save configuration to SPIFFS.
 */
void saveConfig() {
    DynamicJsonDocument doc(1024);
    doc["wifi"]["ssid"] = _wifiSsid;
    doc["wifi"]["password"] = _wifiPassword;
    doc["ntrip"]["host"] = _ntripHost;
    doc["ntrip"]["port"] = _ntripHttpPort;
    doc["ntrip"]["mntpnt"] = _ntripMountPoint;
    doc["ntrip"]["user"] = _ntripUser;
    doc["ntrip"]["passwd"] = _ntripPassword;
    doc["mqtt"]["broker"] = mqttBrokerIP.toString(); // Convert IP address to string
    doc["mqtt"]["user"] = _mqttUser;
    doc["mqtt"]["passwd"] = _mqttPassword;
    doc["mqtt"]["topic"] = _mqttTopic;

    File configFile = SPIFFS.open("/config.json", "w");
    if (!configFile) {
        Serial.println("[ERROR] Failed to open config file for writing");
        return;
    }

    serializeJson(doc, configFile);
}

/**
 * @brief Callback function to set the configuration mode flag.
 */
void saveConfigCallback() {
    configMode = true;
}

/**
 * @brief Enter configuration mode to initialize WiFi.
 * 
 * @param[in] buttonPressed Indicates if the button was pressed to enter configuration mode.
 */
void configurationMode(const bool buttonPressed = false) {
    pixels.setPixelColor(0, pixels.Color(255, 255, 255)); // Orange for configuration portal
    pixels.show();

    // Try to load existing configuration
    loadConfig();

    // Track if WiFi credentials are already set (from SPIFFS)
    bool wifiCredentialsSet = strlen(_wifiSsid) > 0 && strlen(_wifiPassword) > 0;

    WiFiManager wifiManager;

    // Custom parameters
    WiFiManagerParameter custom_host("host", "NTRIP Host", _ntripHost, sizeof(_ntripHost));
    WiFiManagerParameter custom_port("port", "NTRIP Port", String(_ntripHttpPort).c_str(), 6);
    WiFiManagerParameter custom_mntpnt("mntpnt", "NTRIP Mountpoint", _ntripMountPoint, sizeof(_ntripMountPoint));
    WiFiManagerParameter custom_user("user", "NTRIP Username", _ntripUser, sizeof(_ntripUser));
    WiFiManagerParameter custom_passwd("passwd", "NTRIP Password", _ntripPassword, sizeof(_ntripPassword));
    WiFiManagerParameter custom_mqtt_broker("mqtt_broker", "MQTT Broker", _mqttBroker, sizeof(_mqttBroker));
    WiFiManagerParameter custom_mqtt_user("mqtt_user", "MQTT Username", _mqttUser, sizeof(_mqttUser));
    WiFiManagerParameter custom_mqtt_passwd("mqtt_passwd", "MQTT Password", _mqttPassword, sizeof(_mqttPassword));
    WiFiManagerParameter custom_mqtt_topic("mqtt_topic", "MQTT Topic", _mqttTopic, sizeof(_mqttTopic));
    WiFiManagerParameter custom_wifi_ssid("wifi_ssid", "WiFi SSID", _wifiSsid, sizeof(_wifiSsid));
    WiFiManagerParameter custom_wifi_pass("wifi_pass", "WiFi Password (only for initial setup)", _wifiPassword, sizeof(_wifiPassword));

    // Add custom parameters to WiFiManager
    wifiManager.addParameter(&custom_host);
    wifiManager.addParameter(&custom_port);
    wifiManager.addParameter(&custom_mntpnt);
    wifiManager.addParameter(&custom_user);
    wifiManager.addParameter(&custom_passwd);
    wifiManager.addParameter(&custom_mqtt_broker);
    wifiManager.addParameter(&custom_mqtt_user);
    wifiManager.addParameter(&custom_mqtt_passwd);
    wifiManager.addParameter(&custom_mqtt_topic);
    wifiManager.addParameter(&custom_wifi_ssid);
    wifiManager.addParameter(&custom_wifi_pass);

    wifiManager.setSaveConfigCallback(saveConfigCallback);
    wifiManager.setBreakAfterConfig(true);

    // If configuration is empty, start configuration portal
    if (strlen(_wifiSsid) == 0 || strlen(_wifiPassword) == 0 || buttonPressed) {
        wifiManager.startConfigPortal("NTRIPClient_Config");
        wifiManager.stopConfigPortal();
        wifiManager.disconnect();
    } else {
        WiFi.begin(_wifiSsid, _wifiPassword);
        if ((WiFi.waitForConnectResult() != WL_CONNECTED)) {
            wifiManager.startConfigPortal("NTRIPClient_Config");
        }
    }

    if (configMode) {
        Serial.println("[INFO] Storing data to SPIFFS");

        // Always update SSID from portal
        strlcpy(_wifiSsid, custom_wifi_ssid.getValue(), sizeof(_wifiSsid));

        // Only update password if not set yet (first setup)
        if (!wifiCredentialsSet && strlen(custom_wifi_pass.getValue()) > 0) {
            strlcpy(_wifiPassword, custom_wifi_pass.getValue(), sizeof(_wifiPassword));
        }

        // Save other custom parameters as usual
        strlcpy(_ntripHost, custom_host.getValue(), sizeof(_ntripHost));
        _ntripHttpPort = atoi(custom_port.getValue());
        strlcpy(_ntripMountPoint, custom_mntpnt.getValue(), sizeof(_ntripMountPoint));
        strlcpy(_ntripUser, custom_user.getValue(), sizeof(_ntripUser));
        strlcpy(_ntripPassword, custom_passwd.getValue(), sizeof(_ntripPassword));
        strlcpy(_mqttBroker, custom_mqtt_broker.getValue(), sizeof(_mqttBroker));
        strlcpy(_mqttUser, custom_mqtt_user.getValue(), sizeof(_mqttUser));
        strlcpy(_mqttPassword, custom_mqtt_passwd.getValue(), sizeof(_mqttPassword));
        strlcpy(_mqttTopic, custom_mqtt_topic.getValue(), sizeof(_mqttTopic));

        saveConfig();
    }
#ifdef Debug
    printConfig();
#endif
}

/**
 * @brief Initialize or reconnect to the MQTT broker.
 */
void reconnectMQTT() {
    if (mqttClient.connect("NTRIPClient", _mqttUser, _mqttPassword)) {
        Serial.println("connected");
    } else {
        Serial.print("Failed, rc=");
        Serial.print(mqttClient.state());
    }
}
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
void loop() {
    
    // Check WiFi connection status and update WiFi LED
    if (WiFi.status() == WL_CONNECTED) {
        digitalWrite(WIFI_LED, HIGH); // Turn on WiFi LED
    } else {
        digitalWrite(WIFI_LED, LOW); // Turn off WiFi LED
    }

    // Check for button press to activate hotspot
    if (digitalRead(BUTTON_PIN) == LOW) {
        if (!buttonPressed) {
            buttonPressed = true;
            buttonPressTime = millis();
        } else if (millis() - buttonPressTime > BUTTON_PRESS_TIME_MS) { // 3 seconds press
            Serial.println("[INFO] Button pressed for 3 seconds. Entering configuration mode...");
            configurationMode(true);
            buttonPressed = false;
        }
    } else {
        buttonPressed = false;
    }

    // Continuously read and print data from NTRIP server
    bool dataReceived = false;
    while (ntrip_c.available()) {
        char ch = ntrip_c.read();
        Serial2.print(ch);
        dataReceived = true;
    }

    // NTRIP LED blink logic
    if (ntripConnected) {
        if (dataReceived && !ntripLedBlinking) {
            digitalWrite(NTRIP_LED, LOW); // Turn off LED briefly
            ntripLedOffTime = millis();
            ntripLedBlinking = true;
        }
        // Turn LED back on after a short moment (e.g., 10 ms)
        if (ntripLedBlinking && millis() - ntripLedOffTime > 100) {
            digitalWrite(NTRIP_LED, HIGH);
            ntripLedBlinking = false;
        }
    }

    // Update LED based on receiving state
    if (dataReceived) {
        lastReceiveTime = millis();
        pixels.setPixelColor(0, pixels.Color(0, 255, 0)); // Green for data received
        pixels.show();
    } else if (millis() - lastReceiveTime > LED_OFF_TIME_MS) {
        pixels.setPixelColor(0, pixels.Color(0, 0, 255)); // Blue for no data received
        pixels.show();
    }

    // Check if no data received for more than NTRIP_TIMEOUT_MS
    if (millis() - lastReceiveTime > NTRIP_TIMEOUT_MS) {
        Serial.println("[WARNING] No NTRIP data received for more than a minute, restarting...");
        ESP.restart();
    }

    if (!ntrip_c.connected()) {
        digitalWrite(NTRIP_LED, LOW);

        if (millis() - ntripConnectAttemptTime > ntripConnectRetryInterval) {
            Serial.println("[INFO] Attempting to connect to NTRIP server...");
            ntripConnectAttemptTime = millis();
            ntrip_c.connect(_ntripHost, _ntripHttpPort);
        }
        ntripConnected = false;
    } else if (!ntripConnected) {
        Serial.println("[INFO] NTRIP connection established.");
        digitalWrite(NTRIP_LED, HIGH);
        pixels.setPixelColor(0, pixels.Color(0, 0, 255)); // Blue for NTRIP connected and receiving
        pixels.show();

        ntrip_c.reqRaw(_ntripHost, _ntripHttpPort, _ntripMountPoint, _ntripUser, _ntripPassword);

        ntripConnected = true;
    }
    
    
    // --- Always process and send serial data regardless of WiFi state ---
    while (Serial2.available()) {
        char ch = Serial2.read();

        // // copy GNSS data to Serial.
        // Serial1.print(ch);

        // When complete NMEA sentence is received parse sentense and process relevant results
        if (ch == '\n') {
            // Ensure that the buffer is "\0" terminated. 
            nmeaBuffer[nmeaBufferIndex] = '\0';
            // Process relevant NMEA sentences
            if (strstr(nmeaBuffer, "$GNGGA") != NULL) {
                
                // // Check if it is time to send GGA sentence to NTRIP server
                // // Send GGA sentence to NTRIP server every GGA_SEND_INTERVAL milliseconds
                // unsigned long currentTime = millis();
                // if (currentTime - lastGGASendTime >= GGA_SEND_INTERVAL) {
                //     ntrip_c.sendGGA(nmeaBuffer); // Send the GGA sentence to NTRIP server
                //     lastGGASendTime = currentTime; // Update the last GGA send time
                // }
                
                // Forward ANY GGA message immediately to the NTRIP caster
                ntrip_c.sendGGA(nmeaBuffer);

                strlcpy(ggaBuffer, nmeaBuffer, sizeof(ggaBuffer)); // Copy GGA sentence to buffer
                ggaReceived = true; // Set flag to indicate that GGA sentence is received

                // mqttClient.publish("ntripclient/gga", ggaBuffer); // Send the GGA sentence to MQTT broker

                #ifdef DEBUG
                // Send GGA data to Serial for debug
                Serial.println(nmeaBuffer); // Send the complete GGA sentence to Serial
                #endif

            } else if (strstr(nmeaBuffer, "$GNRMC") != NULL) { // Recommended Minimum Navigation Information

                strlcpy(rmcBuffer, nmeaBuffer, sizeof(rmcBuffer)); // Copy RMC sentence to buffer
                rmcReceived = true; // Set flag to indicate that RMC sentence is received

                // Send RMC data to Serial for debug
                #ifdef DEBUG
                Serial.println(nmeaBuffer); // Send the complete RMC sentence to Serial
                #endif
            } else if (strstr(nmeaBuffer, "$GNVTG") != NULL) { // Course Over Ground and Ground Speed

                strlcpy(vtgBuffer, nmeaBuffer, sizeof(vtgBuffer)); // Copy VTG sentence to buffer
                vtgReceived = true; // Set flag to indicate that VTG sentence is received

                // Send RMC data to Serial for debug
                #ifdef DEBUG
                Serial.println(nmeaBuffer); // Send the complete VTG sentence to Serial
                #endif

            }

            // reset Index for buffer to restart colecting NMEA sentence
            nmeaBufferIndex = 0;

            // Check if all relevant NMEA sentences are received
            // If all sentences are received, parse the data and send it to the MQTT broker
            if(ggaReceived && rmcBuffer && vtgReceived) {
                // Reset flags
                ggaReceived = false;
                // Because RMC is only used to get the date, it is not necessary to reset the flag
                // rmcReceived = false;
                vtgReceived = false;

                // The NMEA GGA sentence provides latitude and longitude in
                // a specific format, and additional processing is required 
                // to convert it into decimal degrees.
                //
                // NMEA Latitude and Longitude Format:
                // 1. Latitude: ddmm.mmmm (degrees and minutes)
                //    - dd: Degrees (2 digits)
                //    - mm.mmmm: Minutes (up to 4 decimal places)
                // 2. Longitude: dddmm.mmmm (degrees and minutes)
                //    - ddd: Degrees (3 digits)
                //    - mm.mmmm: Minutes (up to 4 decimal places)
                // To convert these values into decimal degrees:
                //  - Decimal Degrees = Degrees + (Minutes / 60)

                // Serial.println(nmeaBuffer); // Send the complete RMC sentence to Serial
                
                // Parse GGA sentence
                // Serial.println(ggaBuffer); // Print the GGA sentence to Serial for debugging
                
                char* token = strtok(ggaBuffer, ",");
                int fieldIndex = 0;
                double latitude = 0.0;
                double longitude = 0.0;
                double altitude = 0.0;
                double ageOfDifferentialData = 0.0;
                int fixType = 0;
                int satellites = 0;
                double hdop = 0.0;
                char timeBuffer[11] = {0};
                char latDirection = '\0';
                char lonDirection = '\0';
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

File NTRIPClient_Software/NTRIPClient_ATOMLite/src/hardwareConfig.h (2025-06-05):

/*!
 * \file harwareConfig.h
 * \brief Header file with hardware configuration and settings for ATOM-Lite ESP32 board
 *
 * \author Remko Welling (remko.welling@han.nl)
 * \date 5-6-2025
 *
 * 
 */

#ifndef HARDWARECONFIG_H
#define HARDWARECONFIG_H

// Define brightness level (10% of maximum brightness)
#define LED_BRIGHTNESS 25   ///< Brightness level (0-255, where 255 is 100%)

// NeoPixel LED configuration
#define LED_PIN 27          ///< GPIO 38 for the onboard WS2812 RGB LED
#define NUMPIXELS 1         ///< Number of NeoPixels

// Button configuration
#define BUTTON_PIN 39       ///< GPIO for button input

// Second serial interface for NTRIPClient
#define TXD2_PIN 22         ///< GPIO18 for UART2 RX
#define RXD2_PIN 21         ///< GPIO17 for UART2 TX

// GPIO Serial1 (Telemetry unit)
#define TXD1_PIN 19         ///< Corrected to GPIO19 for UART1 TX
#define RXD1_PIN 23         ///< Corrected to GPIO20 for UART1 RX

#define WIFI_LED 25         //</ GPIO9 for WiFi LED
#define NTRIP_LED 23        ///< GPIO10 for NTRIP LED
#define MQTT_LED 33         ///< GPIO11 for MQTT LED
#define FIX_RTKFLOAT_LED 25 ///< GPIO12 for FIX RTK-FLOAT LED
#define FIX_RTK_LED 25  

#define BUTTON_PRESS_TIME_MS 3000   ///< Time in milliseconds to hold button to enter configuration mode

#define LED_OFF_TIME_MS 100         ///< Time in milliseconds to turn off LED after last data received
#define NTRIP_TIMEOUT_MS 60000      ///< Time in milliseconds to reset system if no NTRIP data is received

const unsigned long GGA_SEND_INTERVAL = 300000; ///< 5 minutes in milliseconds

#endif // HARDWARECONFIG_H

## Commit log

2025-03-21 Working code with led indication of progress
2025-03-21 Working portal. Starts in normal operation after 3 sec. button press, at boot when pressing the button.
2025-03-26 start documentation on ESP32-S3-Pico
2025-03-26 Update documentation and add submodule for Wemos boards
2025-03-26 Added initial KiCad schema
    [NTRIPClientBoardWemosS3_ESP32-S3.kicad_pcb, NTRIPClientBoardWemosS3_ESP32-S3.kicad_sch]
2025-03-26 Added my kicad library as submodule
2025-03-26 Change organization on mylibrary for KiCad
2025-03-26 Added Kicad component
2025-03-27 Added component and footprint to KiCad
2025-03-30 Start drawing PCB
    [NTRIPClientBoardWemosS3_ESP32-S3.kicad_pcb, NTRIPClientBoardWemosS3_ESP32-S3.kicad_sch]
2025-04-02 updated NMEA parsing and added correction
    [main.cpp]
2025-04-02 Solved issue with parsing of NMEA sentences, added age of correction data, and updated documentation
    [main.cpp]
2025-04-13 Updated PCB for LOLIN S3 WEMOS board to version 1.0
    [NTRIPClientBoardWemosS3_ESP32-S3.kicad_pcb, NTRIPClientBoardWemosS3_ESP32-S3.kicad_sch]
2025-05-09 Update code base to version 0.9 for debugging speed issue.
    [hardwareConfig.h, main.cpp]
2025-05-09 Solved issue with speed and made solution independent form GNSS receiver
    [main.cpp]
2025-05-09 Update to 0.9.2, added DTR for logger
    [NTRIPClientBoardWemosS3_ESP32-S3.kicad_pcb]
2025-05-09 Corrected time use 2 or 3 characters for milliseconds
    [main.cpp]
2025-05-10 corrected request of mount points so they will be provided when using credentials to the caster
    [NTRIPClient.cpp, main.cpp]
2025-05-11 corrected request of mount points so they will be provided when using credentials to the caster Added Atom-Lite M5 to PCB design
    [NTRIPClientBoardWemosS3_ESP32-S3.kicad_pcb, NTRIPClientBoardWemosS3_ESP32-S3.kicad_sch]
2025-06-05 Corrected software for PCB, removed blocking parts to start immediate sending of time removed AP
    [hardwareConfig.h, main.cpp]
2025-06-20 corrected wifi password management
    [main.cpp]
